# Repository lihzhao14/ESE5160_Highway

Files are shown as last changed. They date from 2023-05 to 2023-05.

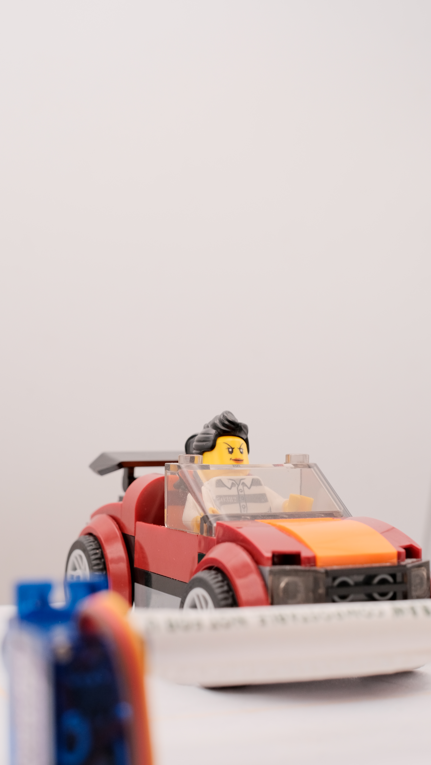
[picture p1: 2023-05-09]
images/car.jpg

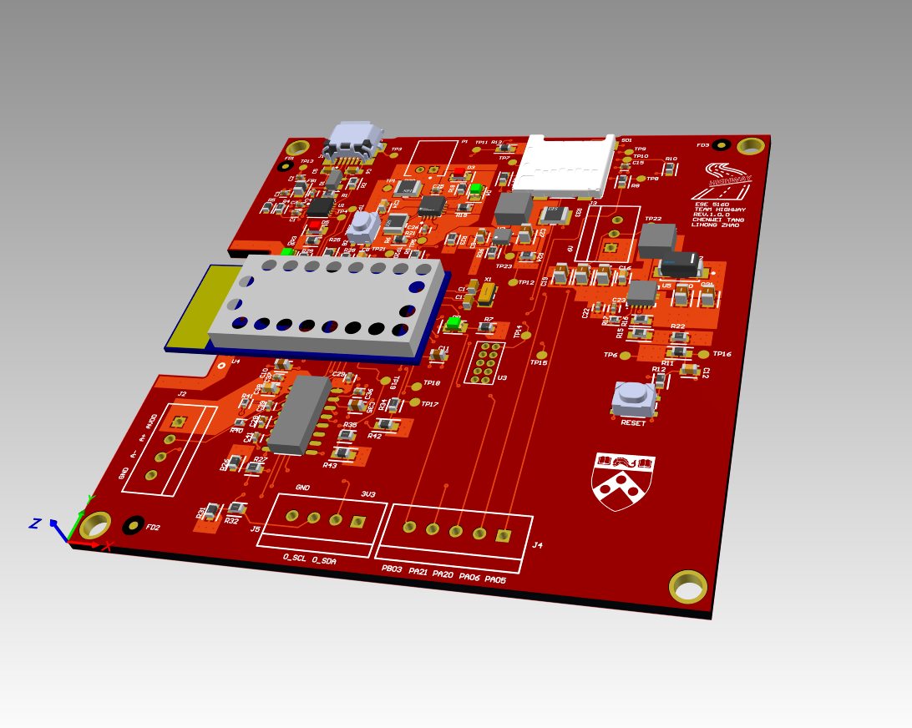
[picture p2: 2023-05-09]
pcb/pcb_image/pcb.png

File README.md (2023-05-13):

University of Pennsylvania, Highway
    
    Team Name: HIGHWAY
    Team Members: Lihong Zhao and Chenwei Tang  
    Tested on: 1. Lenovo Legion 5 Pro 16" Laptop, Windows11 
               2. HP Victus 15 Laptop, Windows11 
             
### DEVPOST-[ESE5160 IoT Highway Toll Station Charging System](https://devpost.com/software/ese5160-iot-highway-toll-station-charging-system)

- PCB files is in folder [pcb](https://github.com/lihzhao14/ESE5160_Highway/tree/main/pcb).
- Microchip Studio project for the SAM W25 is in folder [code_for_SAWM25](https://github.com/ese5160/a13-final-submission-group-ese5160_highway/tree/main/code_for_SAWM25).
- The code worked on our own PCBA is in folder [code_Highway](https://github.com/ese5160/a13-final-submission-group-ese5160_highway/tree/main/code_Highway).
- Node-RED source code is called [highway_flows.json](https://github.com/ese5160/a13-final-submission-group-ese5160_highway/blob/main/highway_flows.json).
- [Demo](https://www.youtube.com/watch?v=WNLnZ9LdI3s)

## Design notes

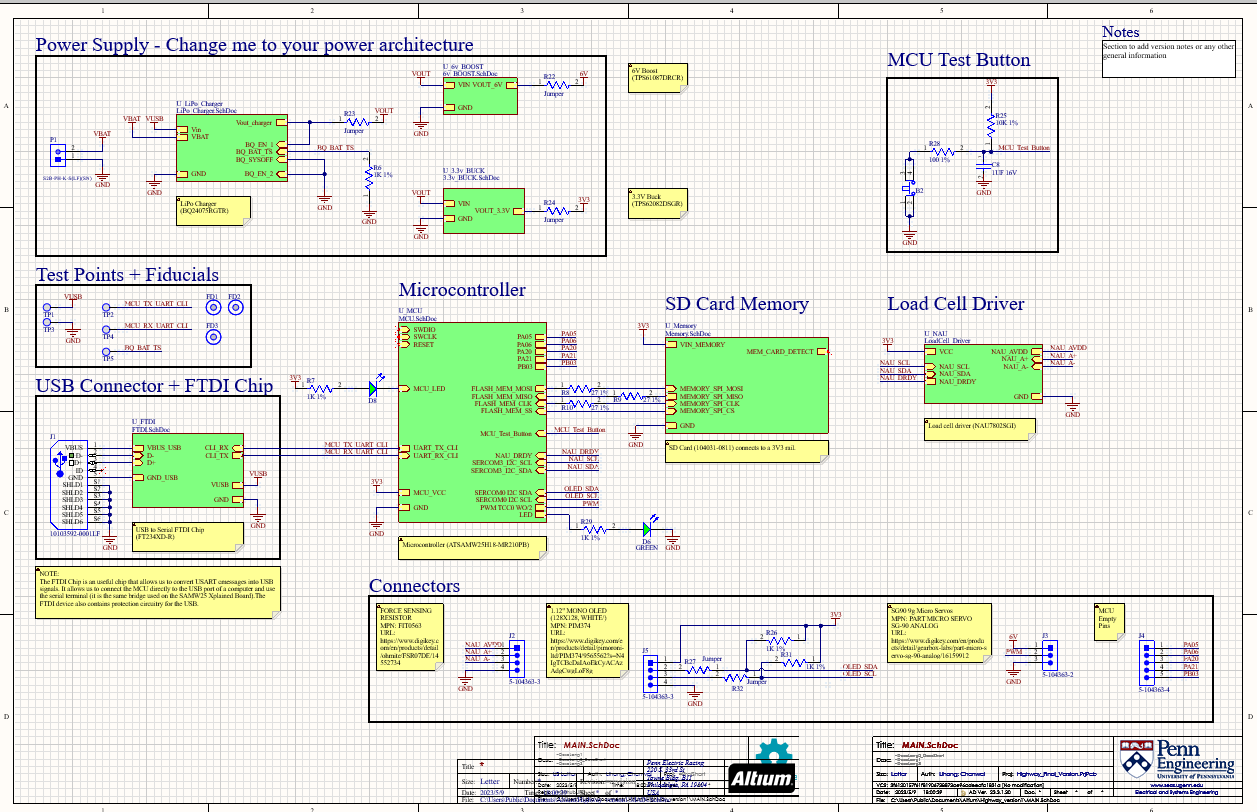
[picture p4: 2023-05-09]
pcb/pcb_image/schematic.png

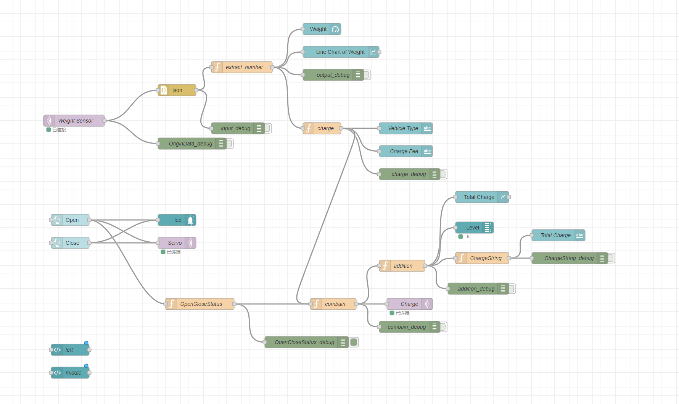
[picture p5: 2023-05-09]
images/node-red.png

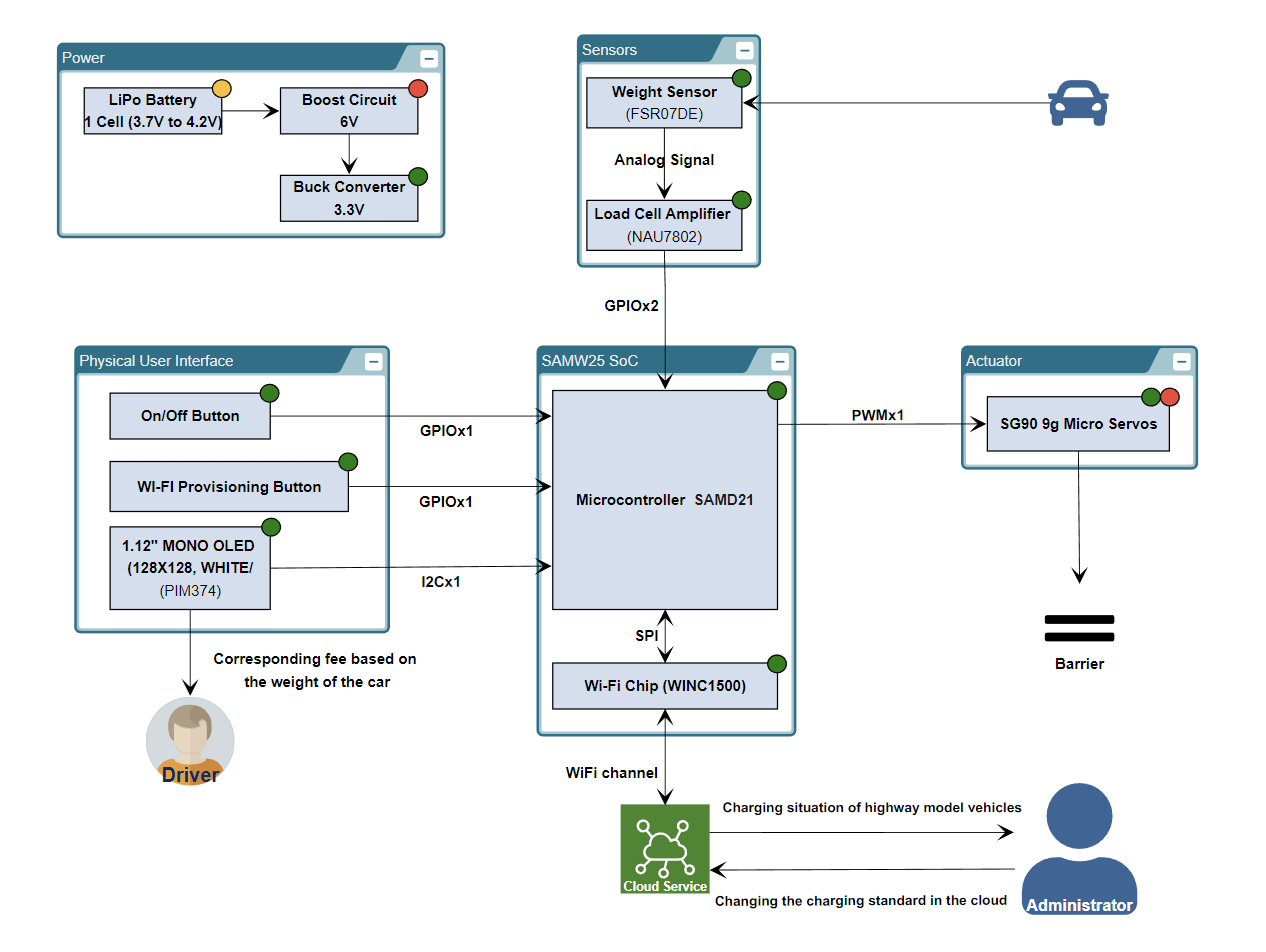
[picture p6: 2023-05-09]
images/flow.png

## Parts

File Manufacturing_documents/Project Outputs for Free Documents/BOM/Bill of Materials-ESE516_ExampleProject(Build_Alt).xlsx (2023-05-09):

Line # | Name | Description | Designator | Quantity | Manufacturer 1 | Manufacturer Part Number 1 | Manufacturer Lifecycle 1 | Supplier 1 | Supplier Part Number 1 | Supplier Unit Price 1 | Supplier Subtotal 1
1 | PTS810SJK250SMTRLFS | Keypad Switch, 1 Switches, SPST, Momentary-tactile, 0.05A, 16VDC, 3.23N, Solder Terminal, Surface Mount-straight | B1, B2 | 2 | ITT C&K | PTS810SJK250SMTRLFS | Volume Production | Digi-Key | CKN10503CT-ND | 0.34 | 0.68
2 | CC0402KPX7R8BB104 | CC0402 100 nF X7R 10.00% 25 V | C1, C3, C7, C15, C22, C29, C36, C37, C39, C41 | 10 | Yageo | CC0402KPX7R8BB104 | Unknown | Mouser | 603-CC0402KPX78BB104 | 0.016 | 0.16
3 | CC0402KPX7R7BB103 | CC0402 10 nF X7R 10.00% 16 V | C2 | 1 | Yageo | CC0402KPX7R7BB103 | Volume Production | Digi-Key | 13-CC0402KPX7R7BB103CT-ND | 0.1 | 0.1
4 | CC0402KRX7R8BB472 | CAP CER 4700PF 25V X7R 0402 | C4, C25, C26 | 3 | Yageo | CC0402KRX7R8BB472 | Unknown | Digi-Key | 311-1039-1-ND | 0.018 | 0.18
5 | CAP 0603 47PF 50V 5% C0G | Capacitor Surface Mount 0603 Footprint 47PF 50V 5% Tolerance Ceramic C0G | C5, C6 | 2 | Yageo Phycomp | CC0603JRNPO9BN470 | Volume Production | Digi-Key | 311-1065-1-ND | 0.1 | 0.2
6 | CC0603KPX7R7BB105 | CC0603 1 uF X7R 10.00% 16 V | C8, C12, C16, C24, C38 | 5 | Yageo | CC0603KPX7R7BB105 | Volume Production | Digi-Key | 13-CC0603KPX7R7BB105CT-ND | 0.14 | 0.7
7 | CC0603MRX5R5BB106 | CAP CER 10UF 6.3V X5R 0603 | C9, C10, C11, C35 | 4 | Yageo | CC0603MRX5R5BB106 | Unknown | Digi-Key | 311-1448-1-ND | 0.22 | 0.88
8 | CC0603JRNPO9BN180 | Chip Capacitor, 18 pF, +/- 5%, 50 V, -55 to 125 degC, 0603 (1608 Metric), RoHS, Tape and Reel | C13, C14 | 2 | Yageo | CC0603JRNPO9BN180 | Unknown | Digi-Key | 311-1061-1-ND | 0.1 | 0.2
9 | CC0805MKX5R8BB226 | CAP CER 22UF 25V X5R 0805 | C17, C18, C19, C20, C21, C27 | 6 | Yageo | CC0805MKX5R8BB226 | Volume Production | Digi-Key | 311-1903-1-ND | 0.41 | 2.46
10 | CC0402KRX7R9BB821 | CAP CER 820PF 50V X7R 0402 | C23 | 1 | Yageo | CC0402KRX7R9BB821 | Volume Production | Digi-Key | 311-1727-1-ND | 0.1 | 0.1
11 | 04025C471KAT2A | General Purpose Ceramic Capacitor, 0402, 470pF, 10%, X7R, 15%, 50V | C28 | 1 | Yageo | CC0402KRX7R9BB471 | Unknown | Digi-Key | 311-1028-1-ND | 0.1 | 0.1
12 | PRTR5V0U2X,215 | Ultra Low Capacitance Double Rail-to-Rail ESD Protection Diode, 5.5 V, 1 pF, -40 to 85 degC, 4-Pin SOT143B, RoHS, Tape and Reel | D1 | 1 | Nexperia | PRTR5V0U2X,215 | Volume Production | Digi-Key | 1727-3884-1-ND | 0.51 | 0.51
13 | B340A-13-F | DIODE SCHOTTKY 40V 3A SMA | D2 | 1 | Diodes | B340A-13-F | Volume Production | Digi-Key | B340A-FDICT-ND | 0.44 | 0.44
14 | LSM0805412V | Single Color LED, RED, 0805 | D3, D5 | 2 | Visual Communications | LSM0805412V | Volume Production | Digi-Key | 28-LSM0805412VCT-ND | 0.47 | 0.94
15 | LSM0805452V | Single Color LED, Green, 0805 | D4, D6, D8 | 3 | Visual Communications | LSM0805452V | Volume Production | Digi-Key | 28-LSM0805452VCT-ND | 0.41 | 1.23
16 | BLM21PG221SN1D | Chip Ferrite Bead, 0805, 220Ω @ 100MHz, 0.045Ω, 25%, 2A | FB1 | 1 | Murata | BLM21PG221SN1D | Unknown | Newark | 73M9167 | 0.102 | 0.102
17 | 10103592-0001LF | Conn Micro USB 2.0 Type B RCP 5 POS 0.65mm Solder RA SMD 5 Terminal 1 Port T/R | J1 | 1 | Amphenol ICC / FCI | 10103592-0001LF | Unknown | Mouser | 649-10103592-0001LF | 0.8 | 0.8
18 | XFL4020-102MEC | Shielded Power Inductor, 1 uH, 64 MHz, -40 to 125 degC, 2-Pin SMD, RoHS, Tape and Reel | L1, L2 | 2 | Coilcraft | XFL4020-102MEC | Volume Production | Mouser | 994-XFL4020-102MEC | 2.68 | 5.36
19 | RMCF0603FT27R0 | 27Ω ±1% 0.1W 0603 Thick Film Chip Resistor AEC-Q200 compliant | R1, R2, R8, R9, R10 | 5 | Stackpole Electronics | RMCF0603FT27R0 | Volume Production | Digi-Key | RMCF0603FT27R0CT-ND | 0.016 | 0.16
20 | RNCP0603FTD1K00 | 1kΩ ±1% 0.125W 0603 High Power Anti-Sulfur Thin Film Chip Resistor | R3, R5, R6, R7, R18, R19, R26, R29, R31 | 9 | Stackpole Electronics | RNCP0603FTD1K00 | Volume Production | Digi-Key | RNCP0603FTD1K00CT-ND | 0.061 | 0.61
21 | RMCF0603ZT0R00 | RES 0 OHM JUMPER 1/10W 0603 | R4, R22, R23, R24, R27, R32, R34, R35, R36 | 9 | Stackpole Electronics | RMCF0603ZT0R00 | Volume Production | Digi-Key | RMCF0603ZT0R00CT-ND | 0.013 | 0.13
22 | RNCP0603FTD10K0 | 10kΩ ±1% 0.125W 0603 High Power Anti-Sulfur Thin Film Chip Resistor | R11, R13, R14, R25, R42, R43 | 6 | Stackpole Electronics | RNCP0603FTD10K0 | Volume Production | Digi-Key | RNCP0603FTD10K0CT-ND | 0.1 | 0.6
23 | RMCF0603FT100R | 100Ω ±1% 0.1W 0603 Thick Film Chip Resistor AEC-Q200 compliant | R12, R28 | 2 | Stackpole Electronics | RMCF0603FT100R | Volume Production | Digi-Key | RMCF0603FT100RCT-ND | 0.016 | 0.16
24 | RMCF0603JT150K | 150kΩ ±5% 0.1W 0603 Thick Film Chip Resistor AEC-Q200 compliant | R15 | 1 | Stackpole Electronics | RMCF0603JT150K | Volume Production | Digi-Key | RMCF0603JT150KCT-ND | 0.1 | 0.1
25 | RMCF0603JT39K0 | 39kΩ ±5% 0.1W 0603 Thick Film Chip Resistor AEC-Q200 compliant | R16 | 1 | Stackpole Electronics | RMCF0603JT39K0 | Volume Production | Digi-Key | RMCF0603JT39K0CT-ND | 0.1 | 0.1
26 | RMCF0402FT68K1 | 68.1kΩ ±1% 0.063W 0402 Thick Film Chip Resistor AEC-Q200 compliant | R17 | 1 | Stackpole Electronics | RMCF0402FT68K1 | Volume Production | Digi-Key | RMCF0402FT68K1CT-ND | 0.1 | 0.1
27 | RMCF1210FT1K13 | 1.13kΩ ±1% 0.5W 1210 Thick Film Chip Resistor AEC-Q200 compliant | R20, R21 | 2 | Stackpole Electronics | RMCF1210FT1K13 | Volume Production | Digi-Key | 738-RMCF1210FT1K13CT-ND | 0.13 | 0.26
28 | RMCF1210FT178K | 178kΩ ±1% 0.5W 1210 Thick Film Chip Resistor AEC-Q200 compliant | R33 | 1 | Stackpole Electronics | RMCF1210FT178K | Volume Production | Digi-Key | 738-RMCF1210FT178KCT-ND | 0.13 | 0.13
29 | RMCF0402FT51R0 | 51Ω ±1% 0.063W 0402 Thick Film Chip Resistor AEC-Q200 compliant | R40, R41 | 2 | Stackpole Electronics | RMCF0402FT51R0 | Volume Production | Digi-Key | RMCF0402FT51R0CT-ND | 0.014 | 0.14
30 | 104031-0811 | Micro SD Card, RA, -25 to 85 degC, 8-Pin SMD, RoHS, Tape and Reel | SD1 | 1 | Molex | 1040310811 | Unknown | Digi-Key | WM6357CT-ND | 2.24 | 2.24
31 | FT234XD-R | USB Bridge, USB to UART USB 2.0 UART Interface 12-DFN (3x3) | U1 | 1 | FTDI | FT234XD-R | Volume Production | Digi-Key | 768-1178-1-ND | 2.26 | 2.26
32 | TPS62082DSGR | Buck Step Down Regulator with 2.3 to 6 V Input and 3.3 V Output, -40 to 85 degC, 8-Pin WSON (DSG), Green (RoHS & no Sb/Br) | U2 | 1 | Texas Instruments | TPS62082DSGR | Volume Production | Mouser | 595-TPS62082DSGR | 1.72 | 1.72
33 | ATSAMW25H18-MR210PB | 2.7 - 4.2 V 65 Mbps 17 dbm 256 kB Flash 32 kB SRAM 802.11 b/g/n Smart Module | U4 | 1 | Microchip | ATSAMW25H18-MR210PB | Unknown | One Stop Electro | 55722508 | 12.8 | 12.8
34 | TPS61087DRCR | Boost Voltage Converter with 2.5 to 6 V Input and 3 to 18.5 V Output, -40 to 85 degC, 10-Pin SON (DRC), Green (RoHS & no Sb/Br) | U5 | 1 | Texas Instruments | TPS61087DRCR | Volume Production | Digi-Key | 296-27012-1-ND | 2.36 | 2.36
35 | BQ24075RGTR | IC LI-ION CHARGE MGMT 16-QFN | U6 | 1 | Texas Instruments | BQ24075RGTR | Volume Production | Mouser | 595-BQ24075RGTR | 2.52 | 2.52
36 | NAU7802SGI | ADC, Delta-Sigma, 24-Bit, 1 Func, 2 Channel, Serial Access, PDSO16 | U9 | 1 | Nuvoton | NAU7802SGI | Volume Production | Digi-Key | NAU7802SGI-ND | 1.71 | 1.71
37 | ABS07-32.768KHZ-T | Crystal 32.768kHz ±20ppm (Tol) 12.5pF FUND 70kΩ 2-Pin CSMD T/R | X1 | 1 | Abracon | ABS07-32.768KHZ-T | Volume Production | Digi-Key | 535-9542-1-ND | 0.72 | 0.72

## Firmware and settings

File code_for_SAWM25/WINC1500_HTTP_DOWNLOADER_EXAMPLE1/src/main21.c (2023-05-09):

/**
 * @file      main.c
 * @brief     Main application entry point
 * @author    Eduardo Garcia
 * @date      2022-04-14
 * @copyright Copyright Bresslergroup\n
 *            This file is proprietary to Bresslergroup.
 *            All rights reserved. Reproduction or distribution, in whole
 *            or in part, is forbidden except by express written permission
 *            of Bresslergroup.
 ******************************************************************************/

/****
 * Includes
 ******************************************************************************/
#include <errno.h>

#include "CliThread/CliThread.h"
#include "ControlThread\ControlThread.h"
#include "DistanceDriver\DistanceSensor.h"
#include "FreeRTOS.h"
#include "IMU\lsm6dso_reg.h"
#include "SeesawDriver/Seesaw.h"
#include "SerialConsole.h"
#include "UiHandlerThread\UiHandlerThread.h"
#include "WifiHandlerThread/WifiHandler.h"
#include "asf.h"
#include "driver/include/m2m_wifi.h"
#include "main.h"
#include "stdio_serial.h"
#include "servo/servo.h"

/****
 * Defines and Types
 ******************************************************************************/
#define APP_TASK_ID 0 /**< @brief ID for the application task */
#define CLI_TASK_ID 1 /**< @brief ID for the command line interface task */

/****
 * Local Function Declaration
 ******************************************************************************/
void vApplicationIdleHook(void);
//!< Initial task used to initialize HW before other tasks are initialized
static void StartTasks(void);
void vApplicationDaemonTaskStartupHook(void);

void vApplicationStackOverflowHook(void);
void vApplicationMallocFailedHook(void);
void vApplicationTickHook(void);

/****
 * Variables
 ******************************************************************************/
static TaskHandle_t cliTaskHandle = NULL;      //!< CLI task handle
static TaskHandle_t daemonTaskHandle = NULL;   //!< Daemon task handle
static TaskHandle_t wifiTaskHandle = NULL;     //!< Wifi task handle
static TaskHandle_t uiTaskHandle = NULL;       //!< UI task handle
static TaskHandle_t controlTaskHandle = NULL;  //!< Control task handle

char bufferPrint[64];  ///< Buffer for daemon task

/**
 * @brief Main application function.
 * Application entry point.
 * @return int
 */
int main(void)
{
    /* Initialize the board. */
    system_init();
	/* test servo */
	//configure_tcc();
	//servo_setDuty(2);
	//while (1)
	//{
		//servo_setDuty(2);
		//delay_ms(2000);
		//servo_setDuty(3);
		//delay_ms(2000);
	//}
    /* Initialize the UART console. */
    InitializeSerialConsole();

    // Initialize trace capabilities
    vTraceEnable(TRC_START);
    // Start FreeRTOS scheduler
    vTaskStartScheduler();

    return 0;  // Will not get here
}

/**
 * function          vApplicationDaemonTaskStartupHook
 * @brief            Initialization code for all subsystems that require FreeRToS
 * @details			This function is called from the FreeRToS timer task. Any code
 *					here will be called before other tasks are initilized.
 * @param[in]        None
 * @return           None
 */
void vApplicationDaemonTaskStartupHook(void)
{
    SerialConsoleWriteString("\r\n\r\n-----ESE516 Main Program-----\r\n");

    // Initialize HW that needs FreeRTOS Initialization
    SerialConsoleWriteString("\r\n\r\nInitialize HW...\r\n");
    if (I2cInitializeDriver() != STATUS_OK) {
        SerialConsoleWriteString("Error initializing I2C Driver!\r\n");
    } else {
        SerialConsoleWriteString("Initialized I2C Driver!\r\n");
    }

    StartTasks();

    vTaskSuspend(daemonTaskHandle);
}

/**
 * function          StartTasks
 * @brief            Initialize application tasks
 * @details
 * @param[in]        None
 * @return           None
 */
static void StartTasks(void)
{
    snprintf(bufferPrint, 64, "Heap before starting tasks: %d\r\n", xPortGetFreeHeapSize());
    SerialConsoleWriteString(bufferPrint);

    // Initialize Tasks here

    if (xTaskCreate(vCommandConsoleTask, "CLI_TASK", CLI_TASK_SIZE, NULL, CLI_PRIORITY, &cliTaskHandle) != pdPASS) {
        SerialConsoleWriteString("ERR: CLI task could not be initialized!\r\n");
    }

    snprintf(bufferPrint, 64, "Heap after starting CLI: %d\r\n", xPortGetFreeHeapSize());
    SerialConsoleWriteString(bufferPrint);

    if (xTaskCreate(vWifiTask, "WIFI_TASK", WIFI_TASK_SIZE, NULL, WIFI_PRIORITY, &wifiTaskHandle) != pdPASS) {
        SerialConsoleWriteString("ERR: WIFI task could not be initialized!\r\n");
    }
    snprintf(bufferPrint, 64, "Heap after starting WIFI: %d\r\n", xPortGetFreeHeapSize());
    SerialConsoleWriteString(bufferPrint);

    if (xTaskCreate(vUiHandlerTask, "UI Task", UI_TASK_SIZE, NULL, UI_TASK_PRIORITY, &uiTaskHandle) != pdPASS) {
        SerialConsoleWriteString("ERR: UI task could not be initialized!\r\n");
    }

    snprintf(bufferPrint, 64, "Heap after starting UI Task: %d\r\n", xPortGetFreeHeapSize());
    SerialConsoleWriteString(bufferPrint);

    //if (xTaskCreate(vControlHandlerTask, "Control Task", CONTROL_TASK_SIZE, NULL, CONTROL_TASK_PRIORITY, &controlTaskHandle) != pdPASS) {
        //SerialConsoleWriteString("ERR: Control task could not be initialized!\r\n");
    //}
    //snprintf(bufferPrint, 64, "Heap after starting Control Task: %d\r\n", xPortGetFreeHeapSize());
    //SerialConsoleWriteString(bufferPrint);
}



void vApplicationMallocFailedHook(void)
{
    SerialConsoleWriteString("Error on memory allocation on FREERTOS!\r\n");
    while (1)
        ;
}

void vApplicationStackOverflowHook(void)
{
    SerialConsoleWriteString("Error on stack overflow on FREERTOS!\r\n");
    while (1)
        ;
}

#include "MCHP_ATWx.h"
void vApplicationTickHook(void)
{
    SysTick_Handler_MQTT();
}

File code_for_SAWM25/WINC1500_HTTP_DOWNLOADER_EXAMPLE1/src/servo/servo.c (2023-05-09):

/*
 * servo.c
 *
 * Created: 4/20/2023 8:48:45 AM
 *  Author: 60267
 */ 
#include "servo.h"
struct tcc_module tcc_instance;
void configure_tcc(void)
{
	struct tcc_config config_tcc;
	tcc_get_config_defaults(&config_tcc, CONF_PWM_MODULE);
	config_tcc.counter.clock_prescaler = TCC_CLOCK_PRESCALER_DIV4;
	config_tcc.counter.period = 0xBA2E;
	config_tcc.compare.wave_generation = TCC_WAVE_GENERATION_SINGLE_SLOPE_PWM;
	config_tcc.compare.match[CONF_PWM_CHANNEL] = (0xBA2E / 2);
	config_tcc.pins.enable_wave_out_pin[CONF_PWM_OUTPUT] = true;
	config_tcc.pins.wave_out_pin[CONF_PWM_OUTPUT]        = CONF_PWM_OUT_PIN;
	config_tcc.pins.wave_out_pin_mux[CONF_PWM_OUTPUT]    = CONF_PWM_OUT_MUX;
	tcc_init(&tcc_instance, CONF_PWM_MODULE, &config_tcc);
	tcc_enable(&tcc_instance);
}


void servo_setDuty(int dutyCycle)
{
	uint32_t compareValue = 0xBA2E / dutyCycle;
	tcc_set_compare_value(&tcc_instance, CONF_PWM_CHANNEL, compareValue);
}

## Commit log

2023-04-20 servo part completed
2023-04-21 Upload the code for OLED screen, servo and NAU7802
2023-04-25 version has some issues
    [CliThread.c, UiHandlerThread.c, WifiHandler.c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]
2023-04-25 servo worked
2023-04-27 a backup simply before DMA
2023-04-27 After pruning, repair wifi queue error
    [CliThread.c, CliThread.h, UiHandlerThread.c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]
2023-05-01 change publish mode
    publish when open servo
2023-05-04 use own MQTT, delete servo flag, and update vTaskDelay(4000)
2023-05-09 put code worked on PCBA in code_Highway
2023-05-09 add code worked on dev board-SAWM25
2023-05-09 Upload pcb files and manufacturing documents
    [3.3v_BUCK.SchDoc, 6v_BOOST.SchDoc, Bill of Materials-ESE516_ExampleProject(Build_Alt).xlsx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]
